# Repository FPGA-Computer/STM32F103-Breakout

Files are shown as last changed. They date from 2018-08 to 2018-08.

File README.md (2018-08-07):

This is a breakout board for the STM32F103 - TQFP48 Package

Eagle CAD/
Sketchup 3D Model/

Hackaday project page is at 
http://hw-by-design.blogspot.com/2018/08/stm32f103-breakout-board.html

Releases: 
forgot 1.5K pullup on USB D+,  fixed in v.3

This work is licensed under a Creative Commons Attribution-
NonCommercial-ShareAlike 4.0 International License.

The full detail of this license is available at: 
http://creativecommons.org/licenses/by-nc-sa/4.0/

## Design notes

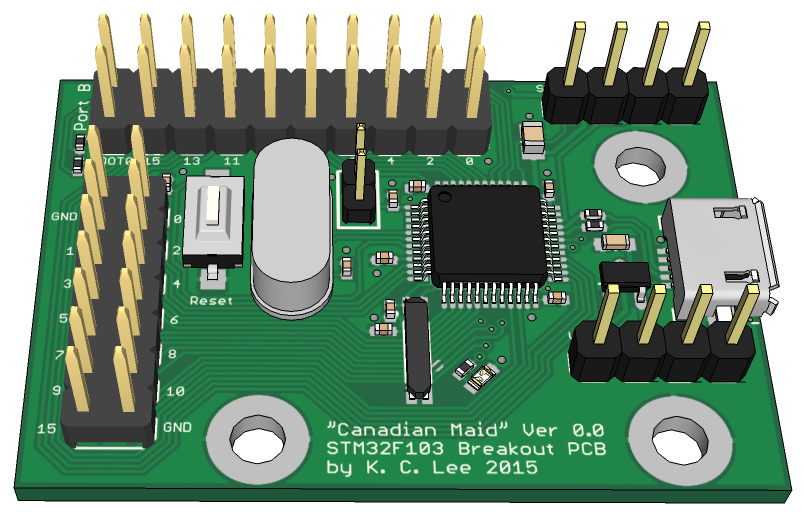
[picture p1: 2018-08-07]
Sketchup 3D Model/PCB.png

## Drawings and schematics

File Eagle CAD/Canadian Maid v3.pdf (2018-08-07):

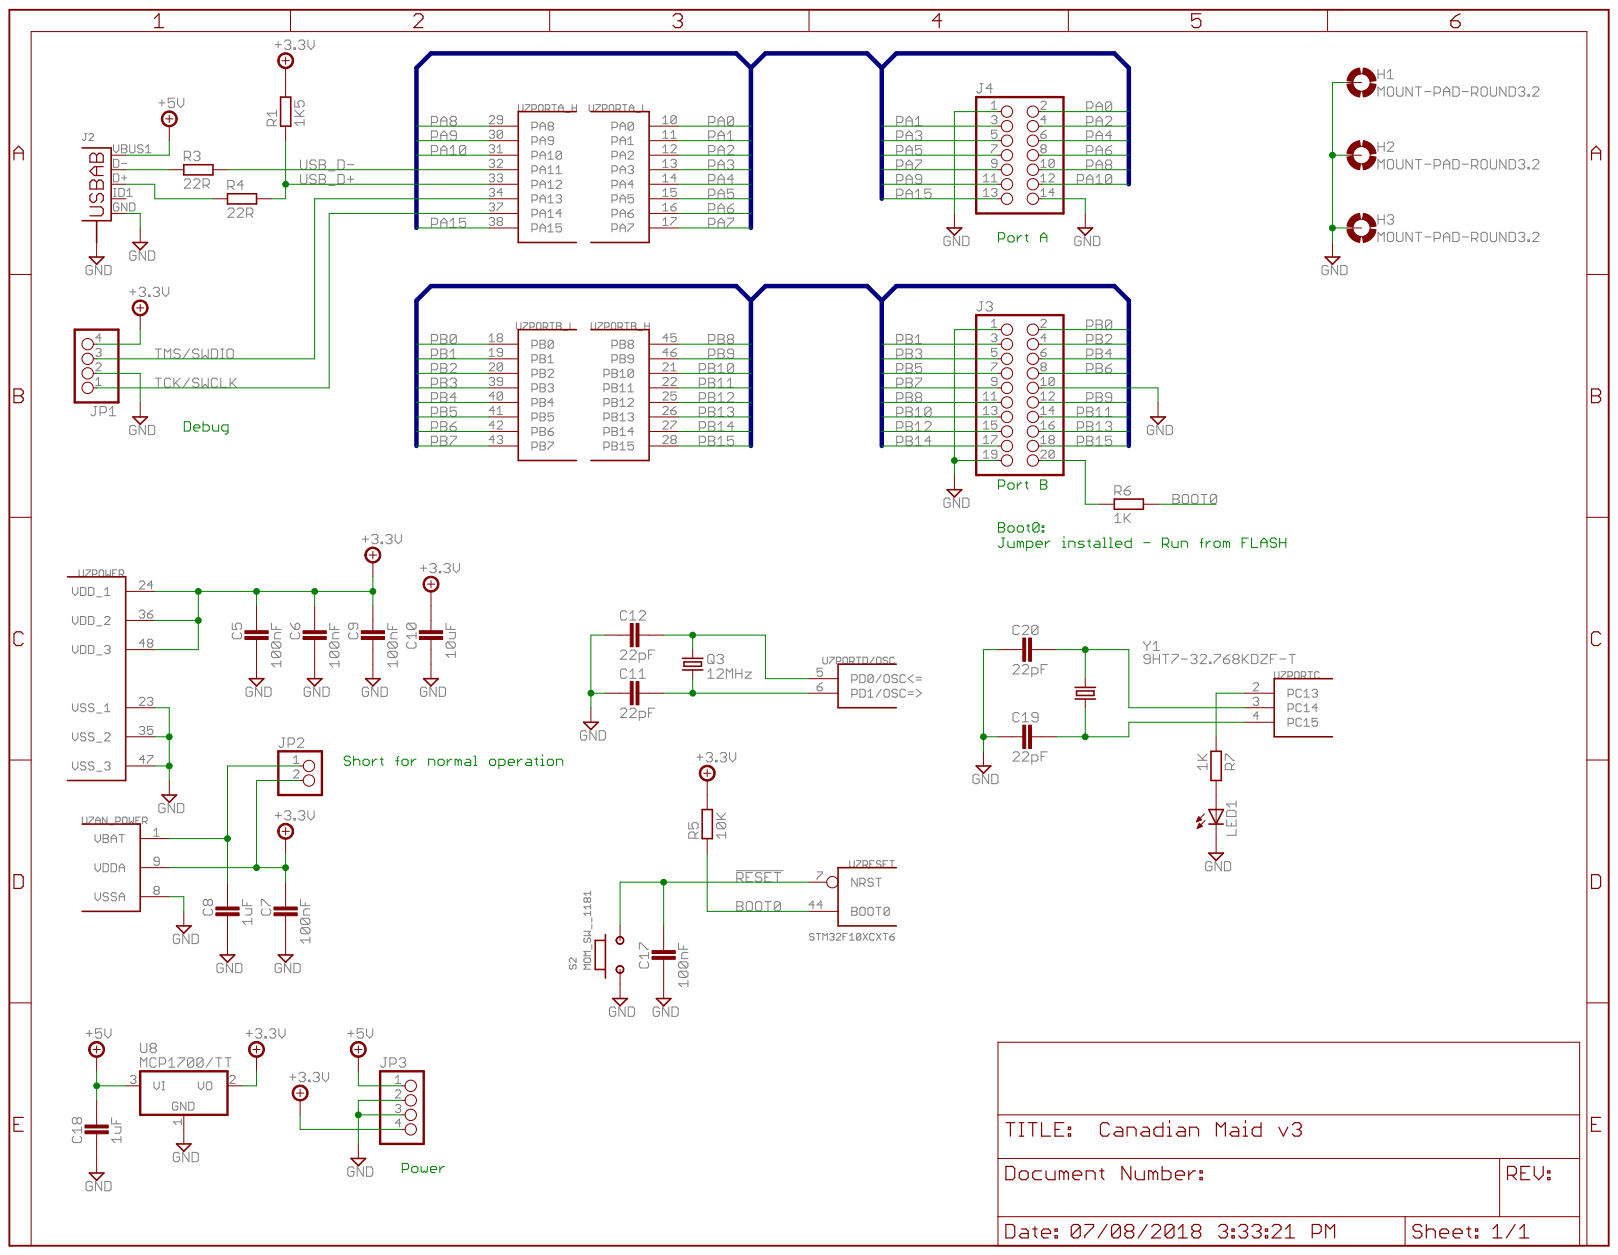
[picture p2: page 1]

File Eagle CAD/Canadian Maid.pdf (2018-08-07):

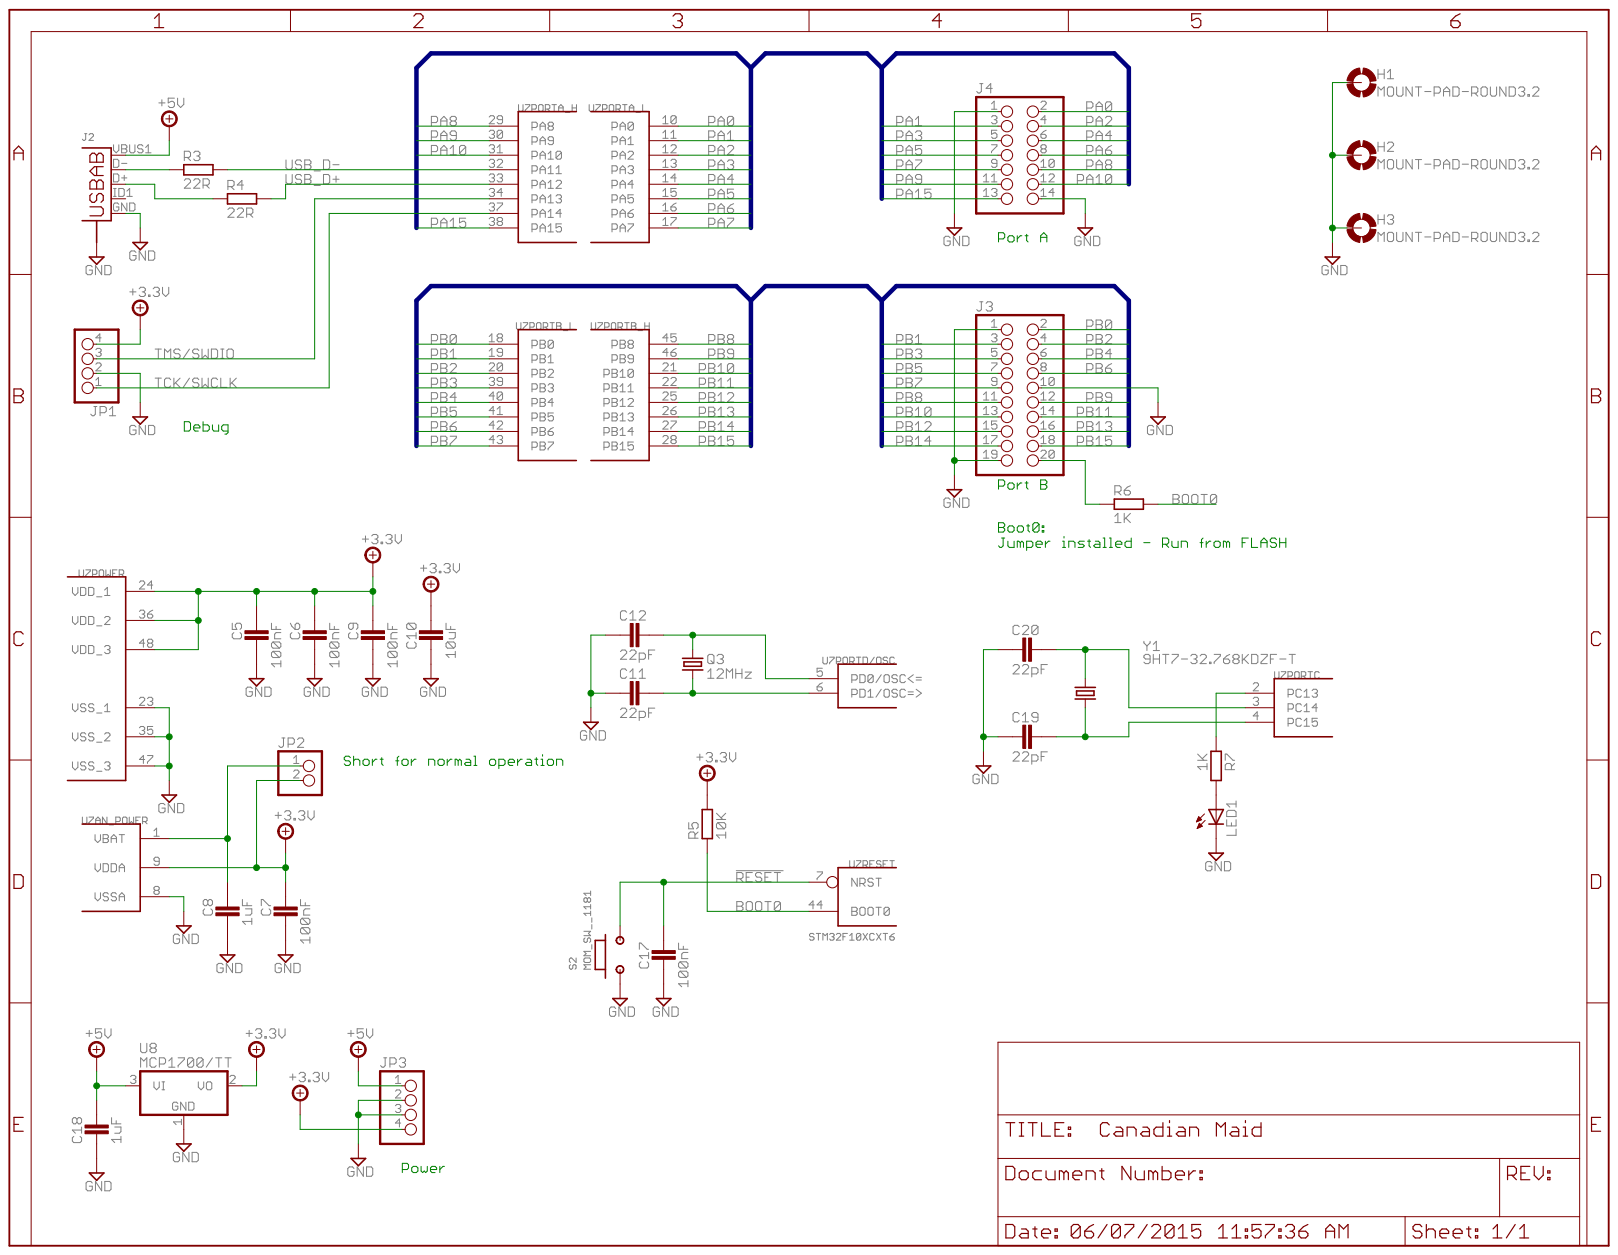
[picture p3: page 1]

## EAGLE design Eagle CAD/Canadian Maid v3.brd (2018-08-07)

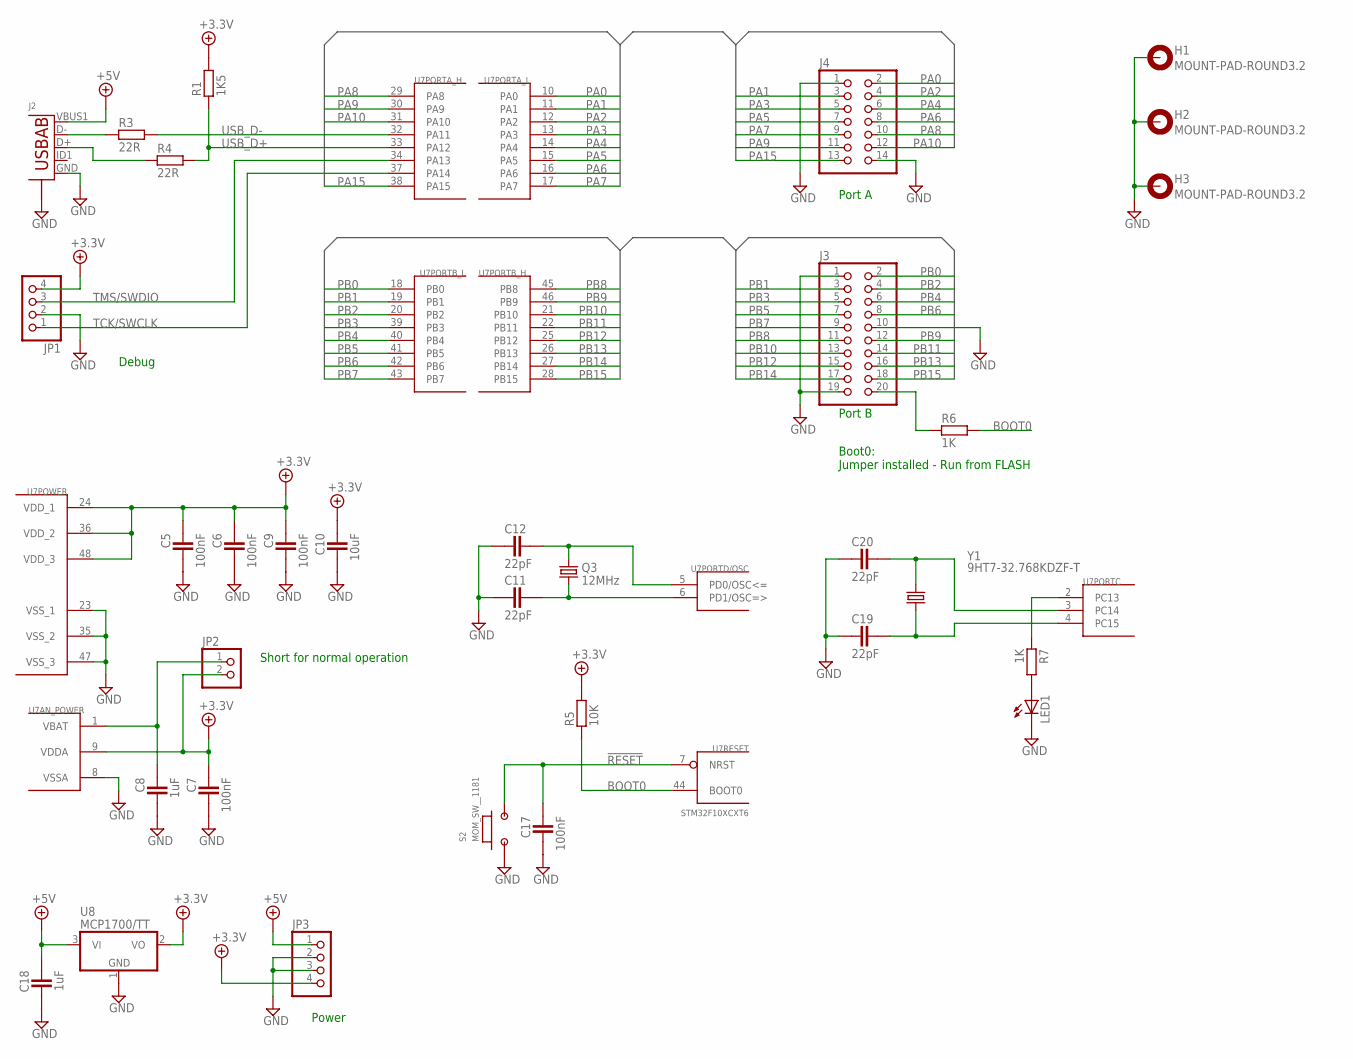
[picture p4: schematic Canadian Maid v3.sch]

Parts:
C5, C6, C7, C9, C17: 100nF; CAPC1005X60N
C8: 1uF; CAPC1005X60N
C10: 10uF; CAPC2012X145AN
C11, C12, C19, C20: 22pF; CAPC1005X60N
C18: 1uF; CAPC1608X92N
H1, H2, H3: MOUNT-PAD-ROUND3.2; 3,2-PAD
J2: USB-ABBG; USB-AB-MICRO-SMD_V03_SF
J3: PINHD-2X10_2.54; 2X10
J4: PINHD-2X7S; 2X07
JP1, JP3: PINHD-1X4_2.54; 1X04
JP2: PINHD-1X2_2.00; 1X02M
LED1: LEDSML0603; SML0603
Q3: 12MHz; HC49U-V
R1: 1K5; RESC1005X40AN
R3, R4: 22R; RESC1005X40AN
R5: 10K; RESC1005X40AN
R6, R7: 1K; RESC1005X40AN
S2: MOM_SW__1181; MOM-1181
U7: STM32F10XCXT6; TQFP48
U8: MCP1700/TT; SOT95P280X135-3N
Y1: 9HT7-32.768KDZF-T; 9HT7

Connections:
!RESET: C17.1, S2.2, U7.7 (NRST)
+3.3V: C5.1, C6.1, C7.1, C9.1, C10.1, JP1.4, JP2.2, JP3.4, R1.2, R5.2, U7.9 (VDDA), U7.24 (VDD_1), U7.36 (VDD_2), U7.48 (VDD_3), U8.2 (VO)
+5V: C18.1, J2.VBUS1 (VBUS), JP3.1, U8.3 (VI)
BOOT0: R5.1, R6.2, U7.44 (BOOT0)
GND: C5.2, C6.2, C7.2, C8.2, C9.2, C10.2, C11.1, C12.1, C17.2, C18.2, C19.1, C20.1, H1.B3,2, H2.B3,2, H3.B3,2, J2.GND, J2.S1 (S), J2.S2 (S), J2.S3 (S), J2.S4 (S), J3.1, J3.10, J3.19, J4.1, J4.14, JP1.2, JP3.2, JP3.3, LED1.C, S2.1, U7.8 (VSSA), U7.23 (VSS_1), U7.35 (VSS_2), U7.47 (VSS_3), U8.1 (GND)
unnamed: J2.D-, R3.1
unnamed: J2.D+, R4.1
unnamed: C8.1, JP2.1, U7.1 (VBAT)
unnamed: C12.2, Q3.2, U7.5 (PD0/OSC<=)
unnamed: C11.2, Q3.1, U7.6 (PD1/OSC=>)
unnamed: J3.20, R6.1
unnamed: C20.2, U7.3 (PC14), Y1.4 (2)
unnamed: C19.2, U7.4 (PC15), Y1.1
unnamed: R7.1, U7.2 (PC13)
unnamed: LED1.A, R7.2
PA0: J4.2, U7.10 (PA0)
PA1: J4.3, U7.11 (PA1)
PA2: J4.4, U7.12 (PA2)
PA3: J4.5, U7.13 (PA3)
PA4: J4.6, U7.14 (PA4)
PA5: J4.7, U7.15 (PA5)
PA6: J4.8, U7.16 (PA6)
PA7: J4.9, U7.17 (PA7)
PA8: J4.10, U7.29 (PA8)
PA9: J4.11, U7.30 (PA9)
PA10: J4.12, U7.31 (PA10)
PA15: J4.13, U7.38 (PA15)
PB0: J3.2, U7.18 (PB0)
PB1: J3.3, U7.19 (PB1)
PB2: J3.4, U7.20 (PB2)
PB3: J3.5, U7.39 (PB3)
PB4: J3.6, U7.40 (PB4)
PB5: J3.7, U7.41 (PB5)
PB6: J3.8, U7.42 (PB6)
PB7: J3.9, U7.43 (PB7)
PB8: J3.11, U7.45 (PB8)
PB9: J3.12, U7.46 (PB9)
PB10: J3.13, U7.21 (PB10)
PB11: J3.14, U7.22 (PB11)
PB12: J3.15, U7.25 (PB12)
PB13: J3.16, U7.26 (PB13)
PB14: J3.17, U7.27 (PB14)
PB15: J3.18, U7.28 (PB15)
TCK/SWCLK: JP1.1, U7.37 (PA14)
TMS/SWDIO: JP1.3, U7.34 (PA13)
USB_D+: R1.1, R4.2, U7.33 (PA12)
USB_D-: R3.2, U7.32 (PA11)

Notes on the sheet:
Short for normal operation
Power
Debug
Port A
Port B
Boot0: Jumper installed - Run from FLASH

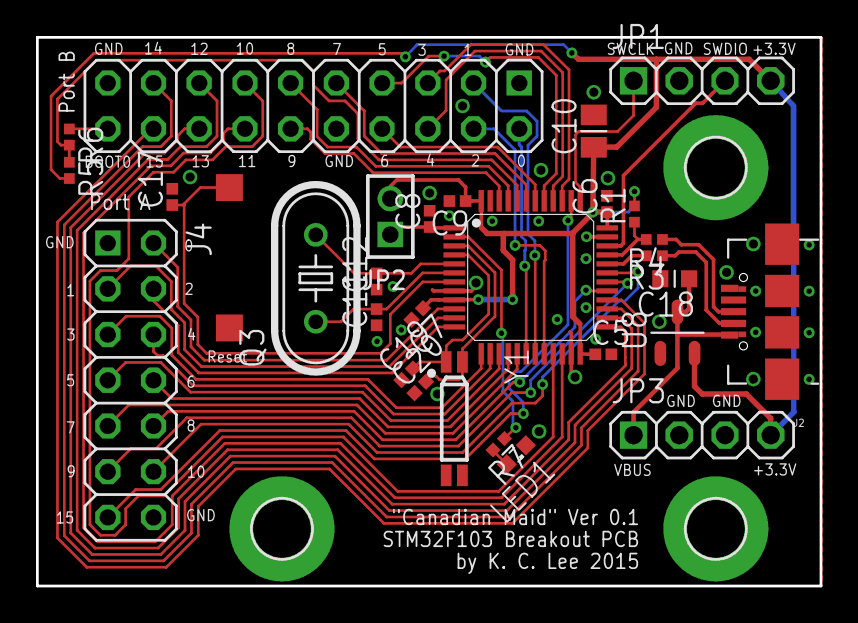
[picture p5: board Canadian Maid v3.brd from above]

Board: 2 copper layers, 43.5 x 30.5 mm, 33 parts (0 on the bottom side), 47 nets.

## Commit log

2018-08-07 Update project hosting
    [Canadian Maid.brd, Canadian Maid.sch]
2018-08-07 latest schematic/layout - fixed USB D+ pullup
    [Canadian Maid v3.brd, Canadian Maid v3.sch]
